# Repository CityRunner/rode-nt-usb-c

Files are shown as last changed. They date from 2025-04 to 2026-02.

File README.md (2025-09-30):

# USB-C Mod for RØDE NT-USB Microphone

Drop-in USB-C daughterboard for the RØDE NT-USB microphone, replacing the original USB-B port.

Designed to fit inside the existing housing - no modification required.
Includes a power LED visible through a transparent 3D-printed insert.
All components are 1206 SMD for easy hand soldering and compact layout.

Watch step-by-step installation on [YouTube:](https://www.youtube.com/embed/nsAjaJf2-Ug)

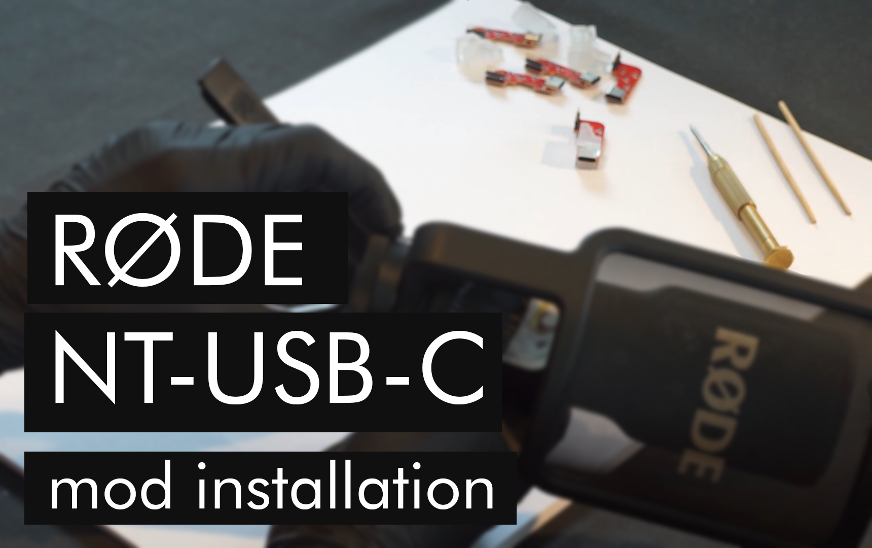
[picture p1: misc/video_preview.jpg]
[](https://www.youtube.com/embed/nsAjaJf2-Ug)

## Features

- **USB-C Connector**: 16-pin edge-mount receptacle.
- **Power Indicator**: Red LED with 220 Ω current-limiting resistor.
- **CC Biasing**: Two 5.11 kΩ pull-down resistors for host detection.

❗**Note:** Tested with the original shielded RØDE SC18 USB-A to USB-C cable. Using cheap USB cables may cause additional noise.

## Images

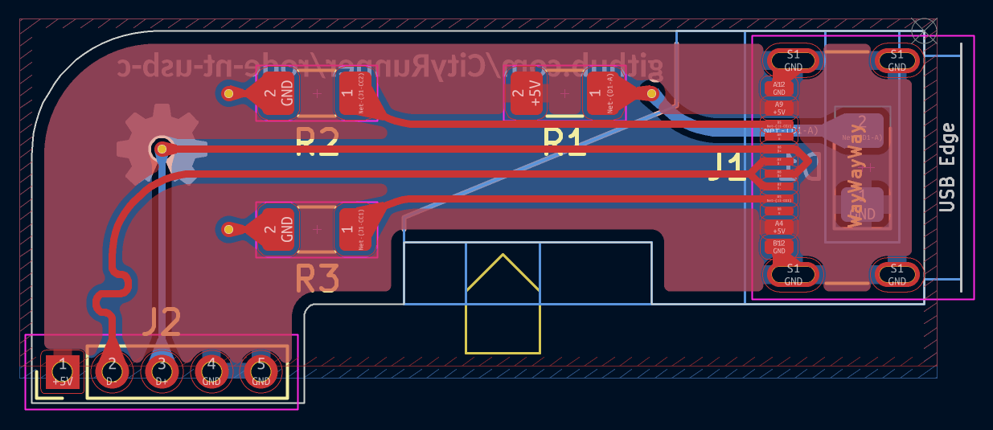
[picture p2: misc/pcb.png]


## Component List:

| Reference | Qty | Value | Digikey Number |
|---|-----|---|---|
| D1 | 1 | LED RED CLEAR 1206 SMD | 754-APTR3216SECK/J3-PRVCT-ND |
| J1 | 1 | CONN RCP USB2.0 TYP C 24P SMD RA | 2073-USB4105-GF-ACT-ND |
| J2 | 1 | CONN BRD STACK 2.00 40POS | 612-TW-40-11-S-S-170-100-ND  |
| R1 | 1 | RES 220 OHM 1% 1/4W 1206 | 311-220FRCT-ND |
| R2, R3 | 2 | RES 5.11K OHM 1% 1/4W 1206 | RMCF1206FT5K11CT-ND |

❗**Important:** The J2 connector must be **exactly** this size (mm):

- **Pitch:** 2.00
- **Length:**
  - **Overall:** 10.08
  - **Post:** 3.22
  - **Stack:** 4.31
  - **Tail:** 2.54

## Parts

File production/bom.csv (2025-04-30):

Designator | Footprint | Quantity | Value | LCSC Part #
D1 | 1206 | 1 | LED
J1 | USB_C_Receptacle_GCT_USB4105-xx-A_16P_TopMnt_Horizontal | 1 | USB_C_Receptacle_USB2.0_16P
J2 | PinHeader_1x05_P2.00mm_Vertical | 1 | Conn_01x05_Pin
R1 | 1206 | 1 | R
R2, R3 | 1206 | 2 | 5.11K

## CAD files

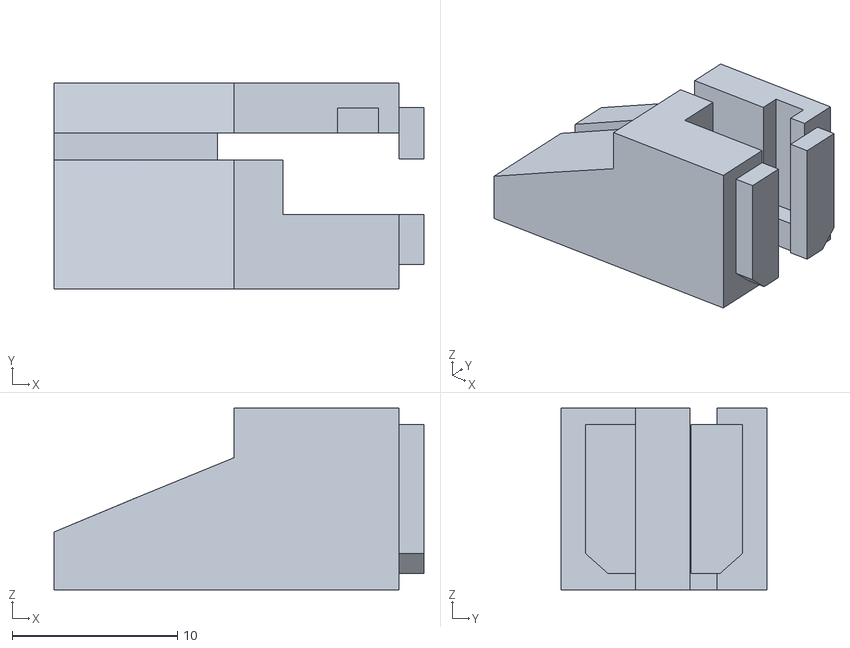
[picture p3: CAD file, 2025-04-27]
model/insert.obj
22.4 x 12.5 x 11.0

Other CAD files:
model/insert.blend

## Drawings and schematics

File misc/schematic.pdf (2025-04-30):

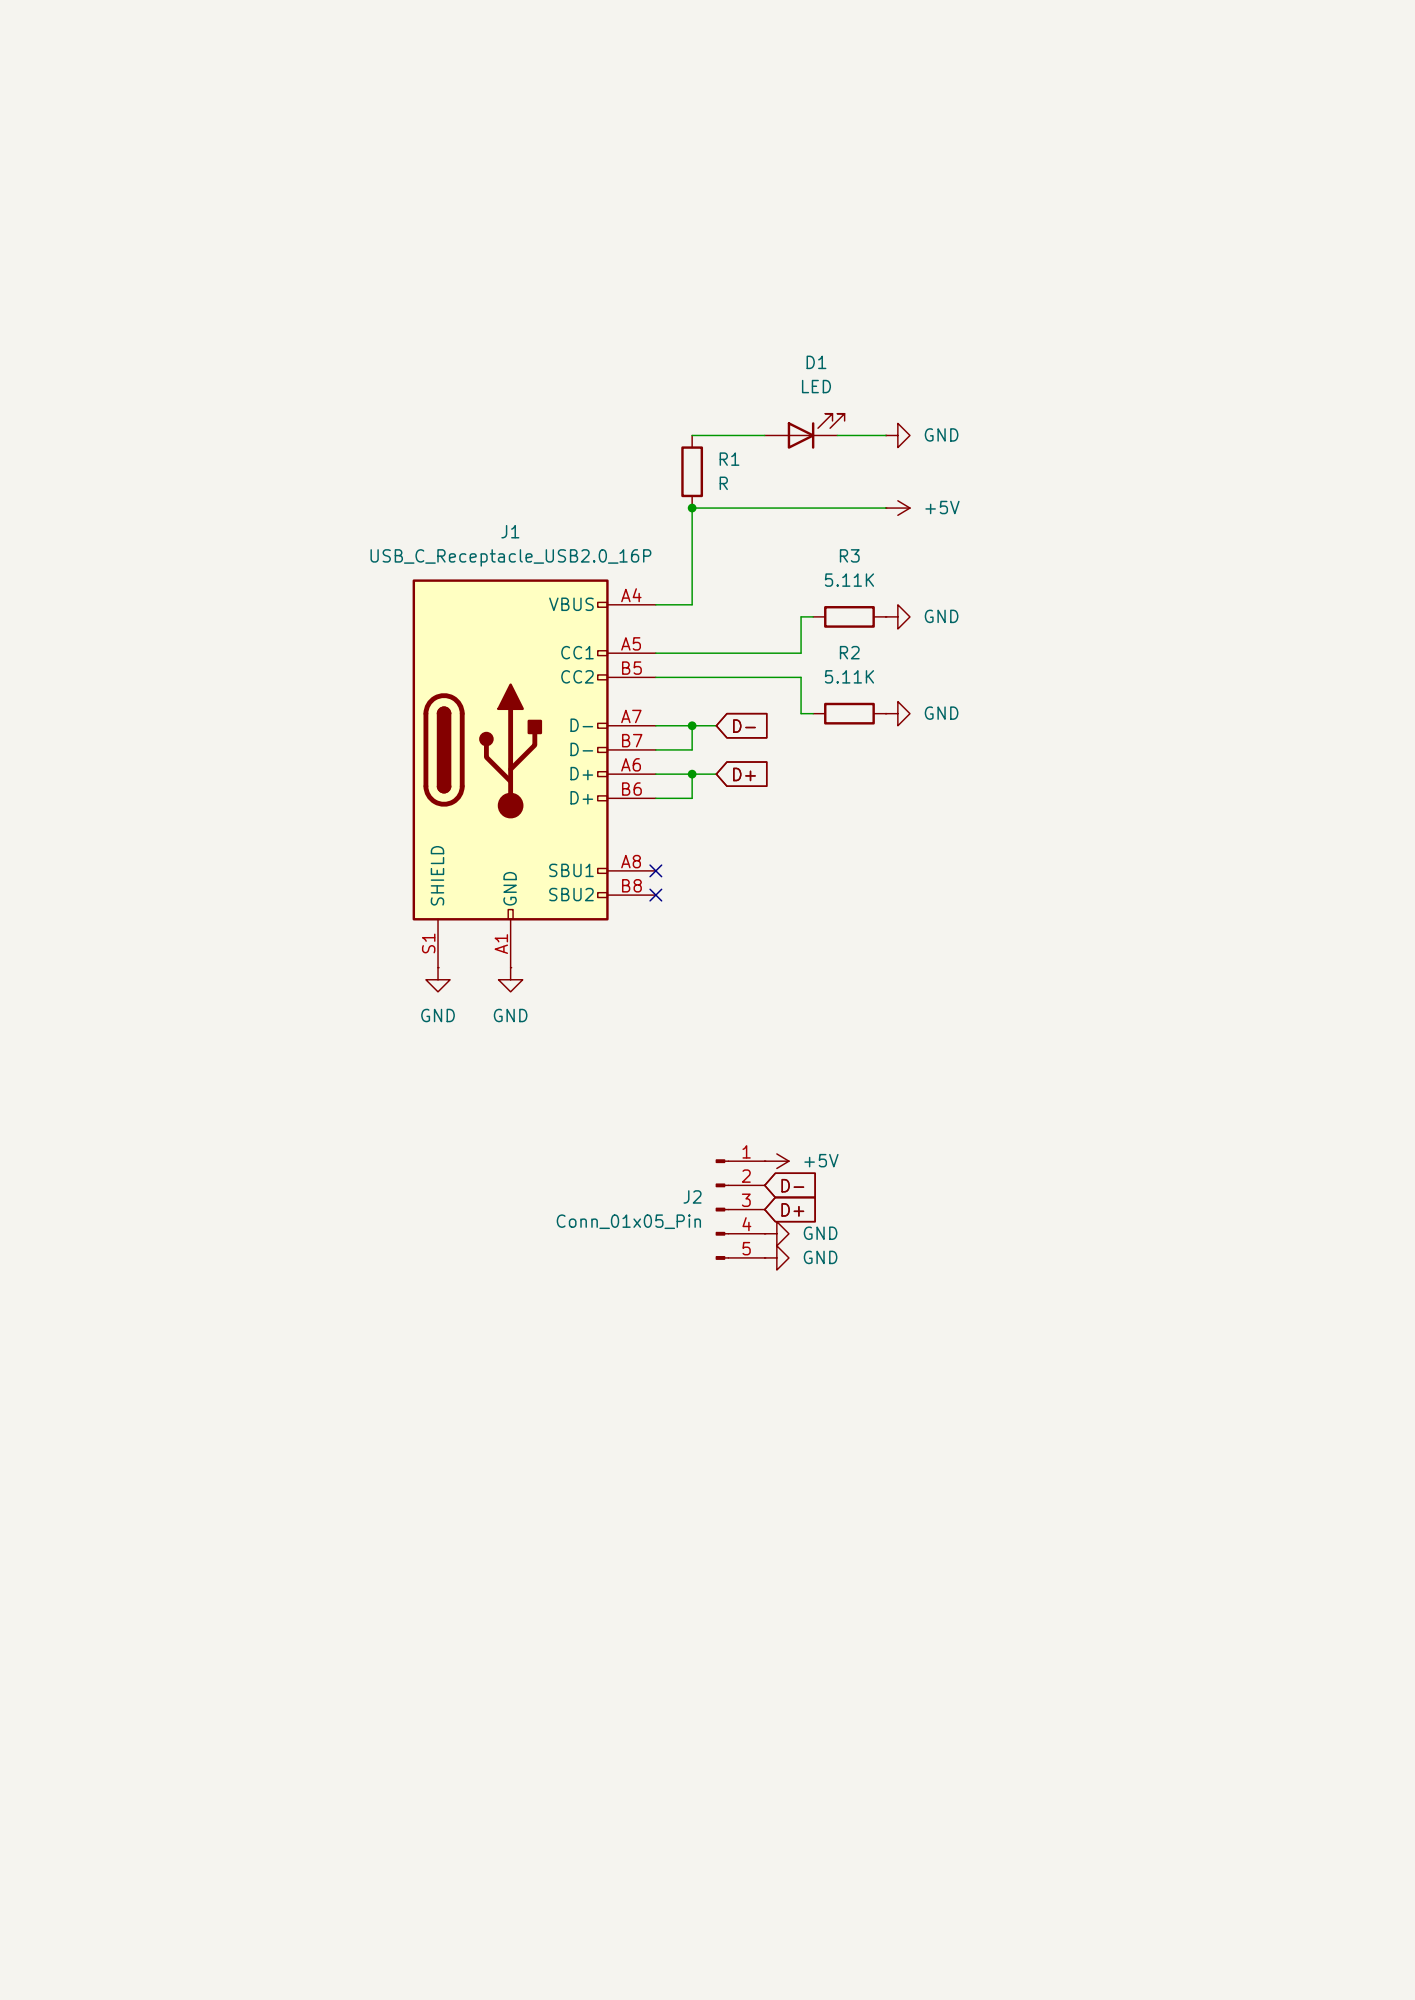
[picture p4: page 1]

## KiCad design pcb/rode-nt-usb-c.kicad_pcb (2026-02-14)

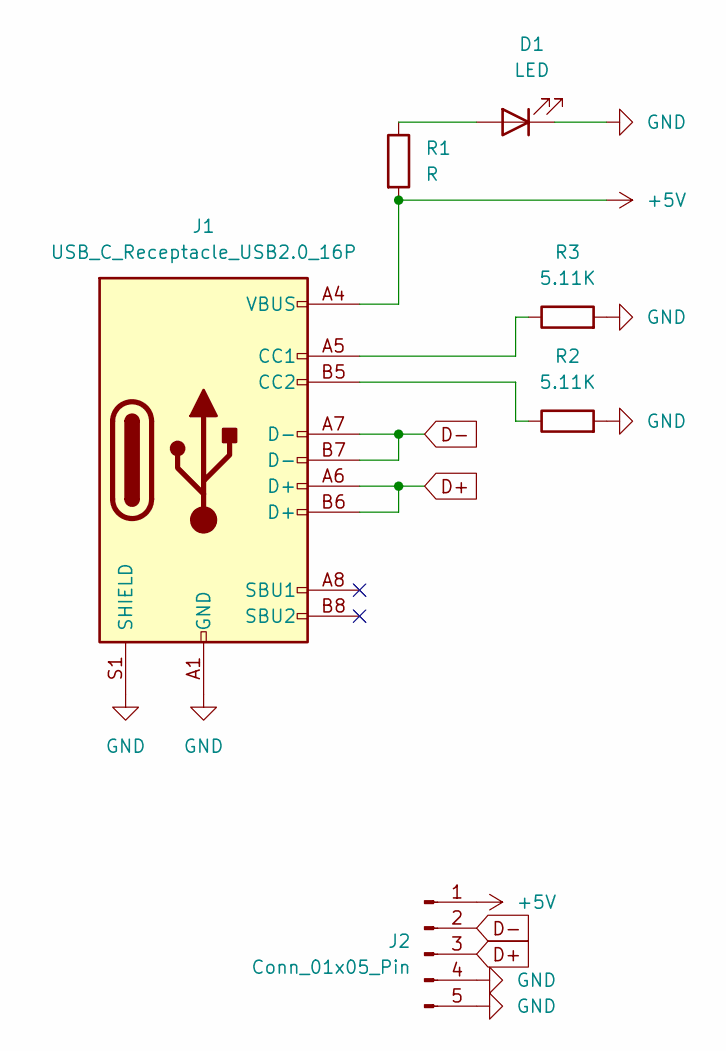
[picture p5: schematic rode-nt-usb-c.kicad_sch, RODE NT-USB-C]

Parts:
D1: LED; LED_1206_3216Metric_Pad1.42x1.75mm_HandSolder
J1: USB_C_Receptacle_USB2.0_16P; USB_C_Receptacle_GCT_USB4105-xx-A_16P_TopMnt_Horizontal
J2: Conn_01x05_Pin; PinHeader_1x05_P2.00mm_Vertical
R1: R; R_1206_3216Metric_Pad1.30x1.75mm_HandSolder
R2, R3: 5.11K; R_1206_3216Metric_Pad1.30x1.75mm_HandSolder

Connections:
+5V: J1.A4 (VBUS), J1.A9 (VBUS), J1.B4 (VBUS), J1.B9 (VBUS), J2.1, R1.2
D+: J1.A6 (D+), J1.B6 (D+), J2.3
D-: J1.A7 (D-), J1.B7 (D-), J2.2
GND: D1.1 (K), J1.A1 (GND), J1.A12 (GND), J1.B1 (GND), J1.B12 (GND), J1.S1 (SHIELD), J2.4, J2.5, R2.2, R3.2
unnamed: D1.2 (A), R1.1
unnamed: J1.A5 (CC1), R3.1
unnamed: J1.B5 (CC2), R2.1

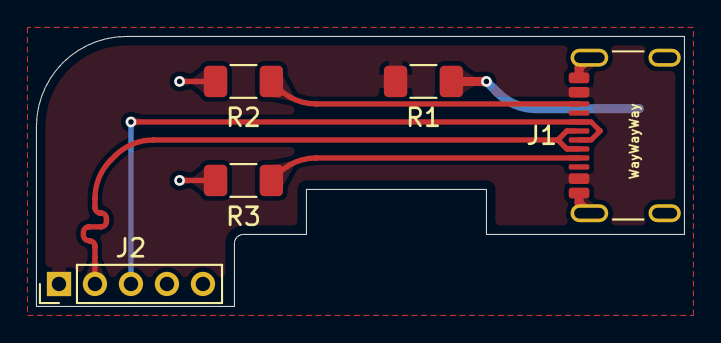
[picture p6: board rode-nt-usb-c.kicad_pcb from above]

Board: 2 copper layers, 36.0 x 15.0 mm, 6 parts (1 on the bottom side), 7 nets.

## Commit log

2025-03-07 Add project files
    [rode-nt-usb-c.kicad_pcb, rode-nt-usb-c.kicad_sch]
2025-03-09 Mod pcb for plastic insert
    [rode-nt-usb-c.kicad_pcb]
2025-03-10 Change cutouts
    [rode-nt-usb-c.kicad_pcb]
2025-03-10 Add LED, reroute
    [rode-nt-usb-c.kicad_pcb]
2025-03-11 Change routing
    [rode-nt-usb-c.kicad_pcb, rode-nt-usb-c.kicad_sch]
2025-03-13 Change usb side
    [rode-nt-usb-c.kicad_pcb]
2025-03-13 Add 3d insert model, change pcb
    [insert.blend, insert.obj, rode-nt-usb-c.kicad_pcb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]
2025-03-13 rearrange files
    [rode-nt-usb-c.kicad_pcb, rode-nt-usb-c.kicad_sch]
2025-03-14 Change size
    [insert.blend, insert.obj]
2025-03-14 Add production files
    [bom.csv, designators.csv, positions.csv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]
2025-04-27 Remove R1, update overall design
    [rode-nt-usb-c.kicad_pcb, rode-nt-usb-c.kicad_sch]
2025-04-27 Change design, multiple adjustments
    [rode-nt-usb-c.kicad_pcb, rode-nt-usb-c.kicad_sch]
2025-04-27 Minor adjustments
    [rode-nt-usb-c.kicad_pcb]
2025-04-27 Adjust size
    [insert.blend, insert.obj]
2025-04-30 Update design
    [rode-nt-usb-c.kicad_pcb]
2025-04-30 Updates production files, misc
    [bom.csv, designators.csv, positions.csv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]
2026-02-14 Adjust pcb net
    [rode-nt-usb-c.kicad_pcb]
